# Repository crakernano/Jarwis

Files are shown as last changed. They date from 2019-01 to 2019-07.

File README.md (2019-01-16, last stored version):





## ¿Qué es Jarwis?
Jarwis es la versión simplificada basada en web del sistema domotico de control JARVIS https://github.com/makespacemadrid/Jarvis

Basado en los modulos de bajo coste NodeMCU y controlado desde una Raspberry Pi que se encarga del automatismo y control de todos los módulo. La comunicación se establece por WiFi y un sistema basado en comunicaciones WEB permite monitorizar distintos parametros tales como:

⋅⋅* Humedad
⋅⋅* Temperatura
⋅⋅* Luz

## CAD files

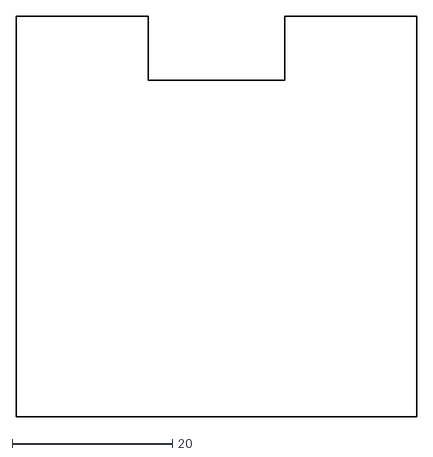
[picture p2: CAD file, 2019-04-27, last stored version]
Modulos/jarwis/placa.dxf
50.0 x 50.0

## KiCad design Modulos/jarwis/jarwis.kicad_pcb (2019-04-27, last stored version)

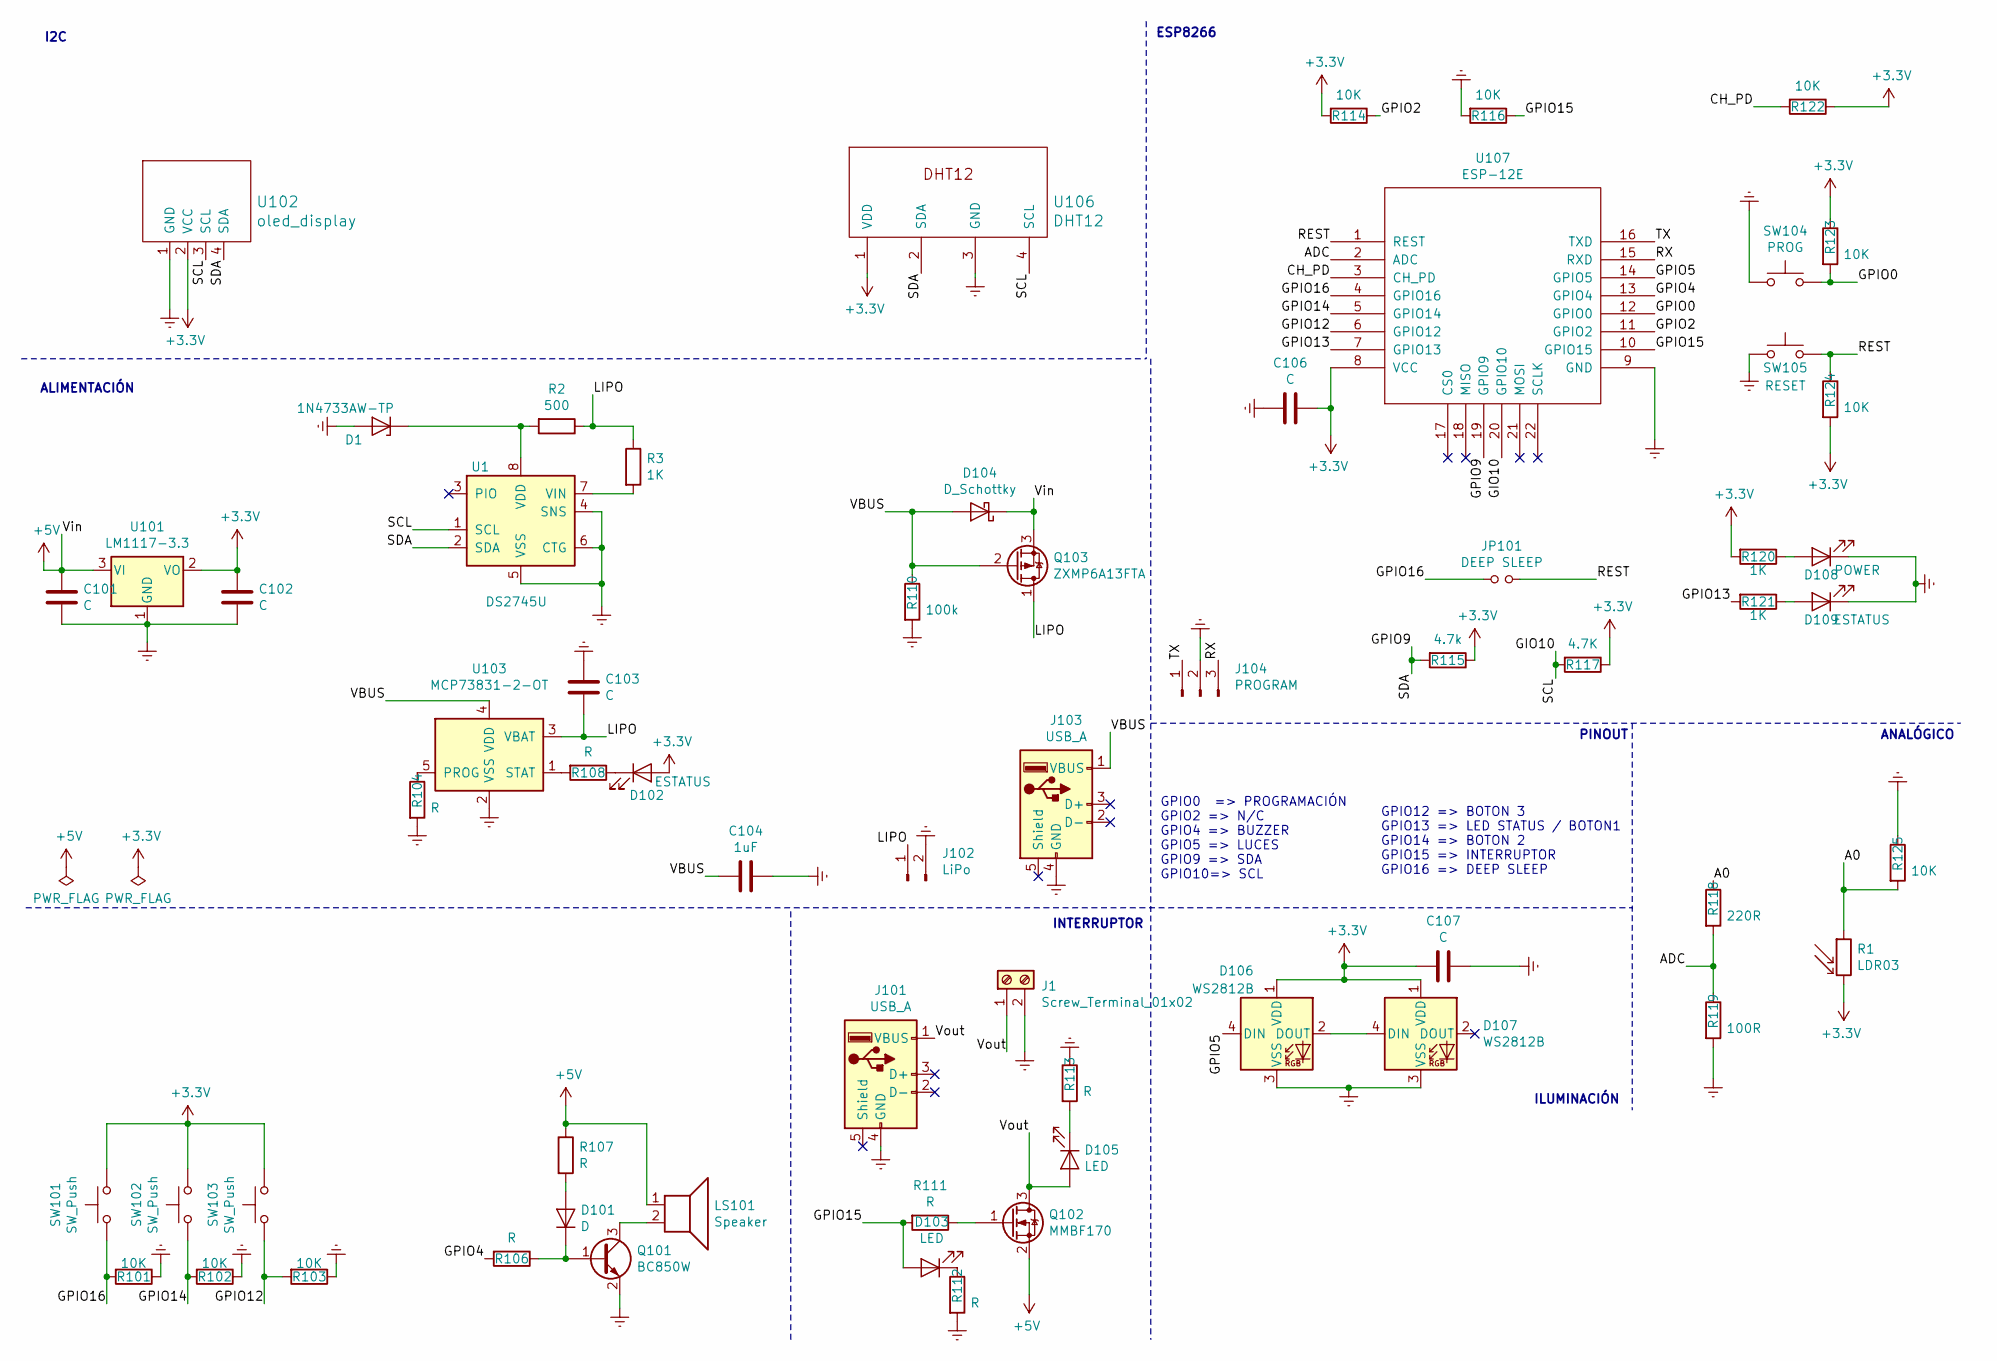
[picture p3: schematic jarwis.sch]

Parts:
C101, C102, C103, C106, C107: C; C_0805_2012Metric_Pad1.15x1.40mm_HandSolder
C104: 1uF; C_0805_2012Metric_Pad1.15x1.40mm_HandSolder
D1: 1N4733AW-TP; D_0805_2012Metric_Pad1.15x1.40mm_HandSolder
D101: D; D_0805_2012Metric_Pad1.15x1.40mm_HandSolder
D102, D109: ESTATUS; LED_0805_2012Metric_Pad1.15x1.40mm_HandSolder
D103, D105: LED; LED_0805_2012Metric_Pad1.15x1.40mm_HandSolder
D104: D_Schottky; D_0805_2012Metric_Pad1.15x1.40mm_HandSolder
D106, D107: WS2812B; LED_WS2812B_PLCC4_5.0x5.0mm_P3.2mm
D108: POWER; LED_0805_2012Metric_Pad1.15x1.40mm_HandSolder
J1: Screw_Terminal_01x02; TerminalBlock_bornier-2_P5.08mm
J101: USB_A; FCI_87520-0010BLF
J102: LiPo; PinHeader_1x02_P2.54mm_Vertical
J103: USB_A; USB_Micro-B_Wuerth_629105150521_CircularHoles
J104: PROGRAM; PinHeader_1x03_P2.54mm_Vertical
JP101: DEEP SLEEP; SolderJumper-2_P1.3mm_Open_RoundedPad1.0x1.5mm
LS101: Speaker; MagneticBuzzer_Kingstate_KCG0601
Q101: BC850W; SOT-323_SC-70
Q102: MMBF170; SOT-23
Q103: ZXMP6A13FTA; SOT-23_Handsoldering
R1: LDR03; R_LDR_7x6mm_P5.1mm_Vertical
R2: 500; R_0805_2012Metric_Pad1.15x1.40mm_HandSolder
R3, R120, R121: 1K; R_0805_2012Metric_Pad1.15x1.40mm_HandSolder
R101, R102, R103, R114, R116, R122, R123, R124, R125: 10K; R_0805_2012Metric_Pad1.15x1.40mm_HandSolder
R104, R106, R107, R108, R111, R112, R113: R; R_0805_2012Metric_Pad1.15x1.40mm_HandSolder
R110: 100k; R_0805_2012Metric_Pad1.15x1.40mm_HandSolder
R115: 4.7k; R_0805_2012Metric_Pad1.15x1.40mm_HandSolder
R117: 4.7K; R_0805_2012Metric_Pad1.15x1.40mm_HandSolder
R118: 220R; R_0805_2012Metric_Pad1.15x1.40mm_HandSolder
R119: 100R; R_0805_2012Metric_Pad1.15x1.40mm_HandSolder
SW101, SW102, SW103: SW_Push; SW_SPST_B3S-1000
SW104: PROG; SW_Tactile_SPST_Angled_PTS645Vx31-2LFS
SW105: RESET; SW_Tactile_SPST_Angled_PTS645Vx31-2LFS
U1: DS2745U; TSSOP-8_3x3mm_P0.65mm
U101: LM1117-3.3; SOT-223-3_TabPin2
U102: oled_display; oled_display_0.96
U103: MCP73831-2-OT; SOT-23-5
U106: DHT12
U107: ESP-12E; ESP-12E_SMD

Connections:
+3V3: C102.1, C106.1, C107.2, D102.2 (A), D106.1 (VDD), D107.1 (VDD), R1.2, R114.2, R115.1, R117.1, R120.2, R122.1, R123.1, R124.2, SW101.2, SW102.2, SW103.2, U101.2 (VO), U102.2 (VCC), U106.1 (VDD), U107.8 (VCC)
+5V: C101.1, D104.1 (K), LS101.1, Q102.2 (S), Q103.3 (S), R107.1, U101.3 (VI)
/A0: R1.1, R118.1, R125.2
/ADC: R118.2, R119.1, U107.2 (ADC)
/CH_PD: R122.2, U107.3 (CH_PD)
/GIO10: R117.2, U1.1 (SCL), U102.3 (SCL), U106.4 (SCL), U107.20 (GPIO10)
/GPIO0: R123.2, SW104.2, U107.12 (GPIO0)
/GPIO2: R114.1, U107.11 (GPIO2)
/GPIO4: R106.2, U107.13 (GPIO4)
/GPIO5: D106.4 (DIN), U107.14 (GPIO5)
/GPIO9: R115.2, U1.2 (SDA), U102.4 (SDA), U106.2 (SDA), U107.19 (GPIO9)
/GPIO12: R103.2, SW103.1, U107.6 (GPIO12)
/GPIO13: R121.2, U107.7 (GPIO13)
/GPIO14: R102.2, SW102.1, U107.5 (GPIO14)
/GPIO15: D103.2 (A), R111.2, R116.1, U107.10 (GPIO15)
/GPIO16: JP101.1, R101.2, SW101.1, U107.4 (GPIO16)
/LIPO: C103.2, J102.1, Q103.1 (D), R2.1, R3.1, U103.3 (VBAT)
/REST: JP101.2, R124.1, SW105.2, U107.1 (REST)
/RX: J104.3, U107.15 (RXD)
/TX: J104.1, U107.16 (TXD)
/VBUS: C104.2, D104.2 (A), J103.1 (VBUS), Q103.2 (G), R110.1, U103.4 (VDD)
/Vout: D105.2 (A), J1.1, J101.1 (VBUS), Q102.3 (D)
Earth: C101.2, C102.2, C103.1, C104.1, C106.2, C107.1, D1.2 (A), D106.3 (VSS), D107.3 (VSS), D108.1 (K), D109.1 (K), J1.2, J101.4 (GND), J102.2, J103.4 (GND), J104.2, Q101.2 (E), R101.1, R102.1, R103.1, R104.2, R110.2, R112.2, R113.1, R116.2, R119.2, R125.1, SW104.1, SW105.1, U1.4 (SNS), U1.5 (VSS), U1.6 (CTG), U101.1 (GND), U102.1 (GND), U103.2 (VSS), U106.3 (GND), U107.9 (GND)
unnamed: D1.1 (K), R2.2, U1.8 (VDD)
unnamed: D101.1 (K), Q101.1 (B), R106.1
unnamed: D101.2 (A), R107.2
unnamed: D102.1 (K), R108.1
unnamed: D103.1 (K), R112.1
unnamed: D105.1 (K), R113.2
unnamed: D106.2 (DOUT), D107.4 (DIN)
unnamed: D108.2 (A), R120.1
unnamed: D109.2 (A), R121.1
unnamed: LS101.2, Q101.3 (C)
unnamed: Q102.1 (G), R111.1
unnamed: R3.2, U1.7 (VIN)
unnamed: R104.1, U103.5 (PROG)
unnamed: R108.2, U103.1 (STAT)

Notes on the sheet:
PINOUT
GPIO0 => PROGRAMACIÓN GPIO2 => N/C GPIO4 => BUZZER GPIO5 => LUCES GPIO9 => SDA GPIO10=> SCL
GPIO12 => BOTON 3 GPIO13 => LED STATUS / BOTON1 GPIO14 => BOTON 2 GPIO15 => INTERRUPTOR GPIO16 => DEEP SLEEP
I2C
ALIMENTACIÓN
ESP8266
ANALÓGICO
INTERRUPTOR
ILUMINACIÓN

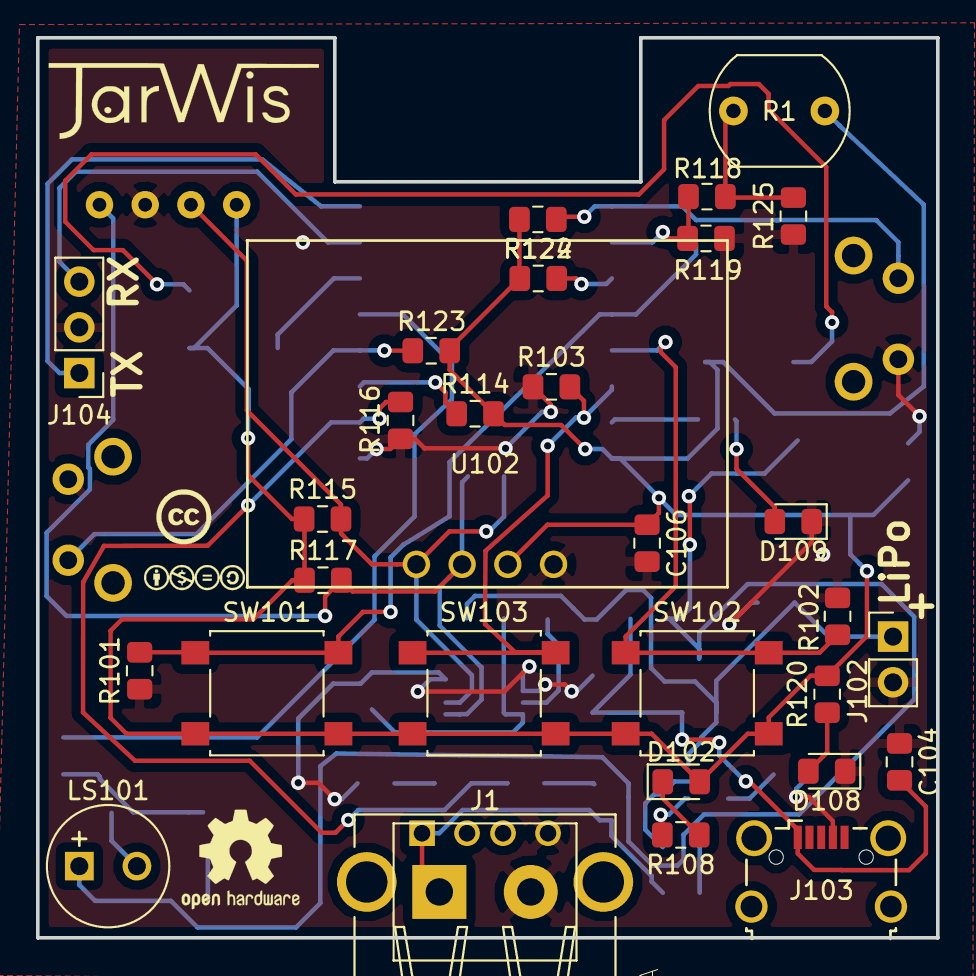
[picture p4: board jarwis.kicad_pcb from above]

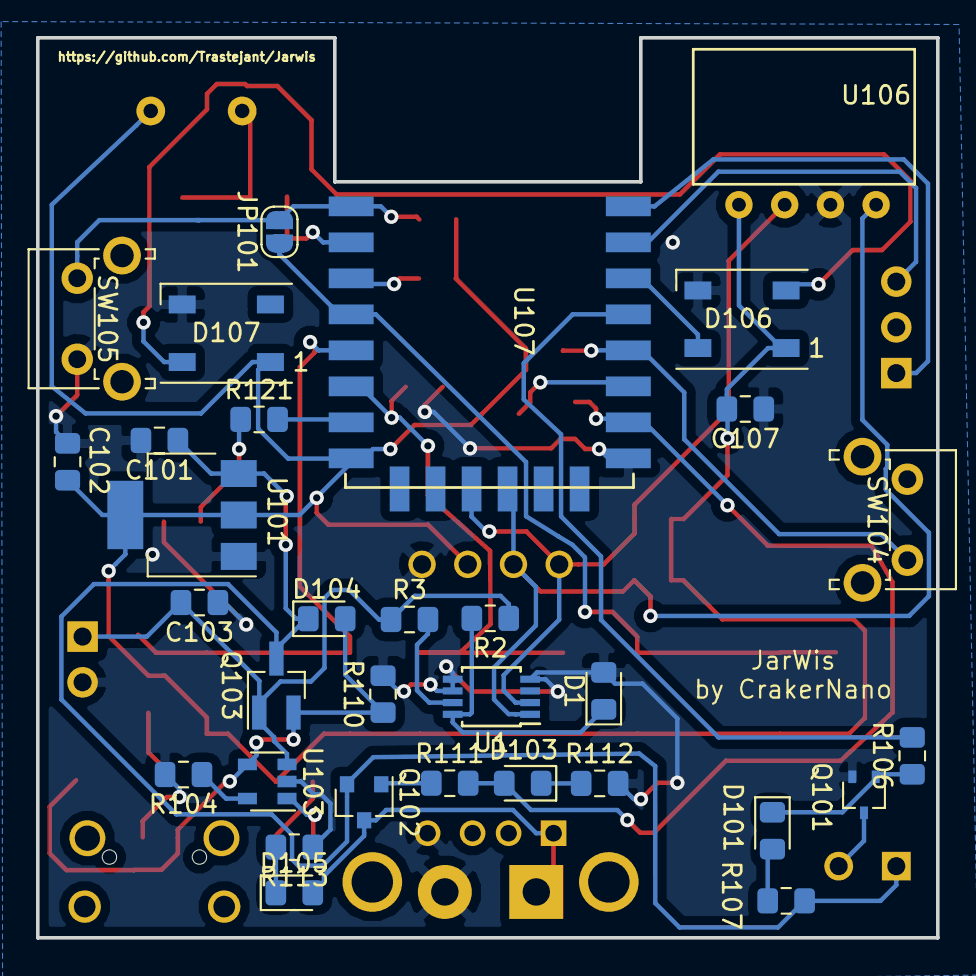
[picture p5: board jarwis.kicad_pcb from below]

Board: 2 copper layers, 50.0 x 50.0 mm, 63 parts (32 on the bottom side), 37 nets.

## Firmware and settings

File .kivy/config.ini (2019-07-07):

[kivy]
keyboard_repeat_delay = 300
keyboard_repeat_rate = 30
log_dir = logs
log_enable = 1
log_level = info
log_name = kivy_%y-%m-%d_%_.txt
window_icon = 
keyboard_mode = 
keyboard_layout = qwerty
desktop = 1
exit_on_escape = 1
pause_on_minimize = 0
kivy_clock = default
default_font = ['Roboto', 'data/fonts/Roboto-Regular.ttf', 'data/fonts/Roboto-Italic.ttf', 'data/fonts/Roboto-Bold.ttf', 'data/fonts/Roboto-BoldItalic.ttf']
log_maxfiles = 100
window_shape = data/images/defaultshape.png
config_version = 20

[graphics]
display = -1
fullscreen = 0
height = 600
left = 0
maxfps = 60
multisamples = 2
position = auto
rotation = 0
show_cursor = 1
top = 0
width = 800
resizable = 1
borderless = 0
window_state = visible
minimum_width = 0
minimum_height = 0
min_state_time = .035
allow_screensaver = 1
shaped = 0


[postproc]
double_tap_distance = 20
double_tap_time = 250
ignore = []
jitter_distance = 0
jitter_ignore_devices = mouse,mactouch,
retain_distance = 50
retain_time = 0
triple_tap_distance = 20
triple_tap_time = 375

[widgets]
scroll_timeout = 250
scroll_distance = 20
scroll_friction = 1.
scroll_stoptime = 300
scroll_moves = 5

[modules]

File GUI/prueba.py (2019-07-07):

 #!/usr/bin/env python3
    # -*- coding: utf-8 -*-

    from kivy.app import App
    from kivy.clock import Clock
    from kivy.uix.screenmanager import ScreenManager, Screen
    from kivy.uix.boxlayout import BoxLayout
    from kivy.properties import ObjectProperty, StringProperty
    import paho.mqtt.client as mqtt
    import RPi.GPIO as GPIO
    import json
    import time, datetime

    class ScreenManagement(ScreenManager):
        pass

    class Main(Screen):
        inoutflow = StringProperty()
        freshexh = StringProperty()
        tacho = StringProperty()
        co2 = StringProperty()
        def setVent(self,percent):
            print('button state is: ', percent)
            message = "{\"flow-rate\":\"" + str(percent) + "\"}"
            mqttc.publish('weigus/attic/attic/ventilation',message)

    class Setup(Screen):
        pass

    class pitouconApp(App):
        def build(self):
            global SM #ScreenManager
            global s
            SM = self.root
            s = SM.get_screen('main')

        def on_start(self):
            global mqttc
            global switch_pin
            switch_pin = 3
            global switch_old
            switch_old = 1
            GPIO.setmode(GPIO.BCM)
            GPIO.setwarnings(False)
            GPIO.setup(switch_pin, GPIO.IN)
            clientID   = "pitoucon"
            brokerIP   = "192.168.1.111"
            brokerPort = 1883
            topic      = "mytopic"
            # Callback if CONNACK response from the server.
            def onConnect(client, userdata, flags, rc):
                print("Connected with result code " + str(rc))
                mqttc.subscribe(topic, 0)  # Subscribe (topic name, QoS)
            # Callback that is executed when we disconnect from the broker.
            def onDisconnect(client, userdata, message):
                print("Disconnected from the broker.")
            # Callback that is executed when subscribing to a topic
            def onSubscribe(client, userdata, mid, granted_qos):
                print('Subscribed on topic.')
            # Callback that is executed when unsubscribing to a topic
            def onUnsubscribe(client, userdata, mid, granted_qos):
                print('Unsubscribed on topic.')
            # Callback that is executed when a message is received.
            def onMessage(client, userdata, message):
                io=message.payload.decode("utf-8")
                if (io[2:6] != "flow") and (io[2:7] != "alive"):
                    try:
                        ioj=json.loads(io)
                        inflowTxt = ioj["inflow"]
                        outflowTxt = ioj["outflow"]
                        inOutTxt = "Temp   Hum      \n" + inflowTxt + "  IN \n\n" + outflowTxt + "  OUT"
                        s.inoutflow = inOutTxt
                        freshTxt = ioj["fresh"]
                        exhaustTxt = ioj["exhaust"]
                        freExTxt = "        Temp   Hum\nFRESH   " + freshTxt + "\n\nEXHAUST " + exhaustTxt
                        s.freshexh = freExTxt
                        tinTxt = ioj["tacho-in"]
                        if tinTxt[2]  == "%":
                            tinTxt = tinTxt[0:2]
                        else:
                            tinTxt = tinTxt[0:3]
                        toutTxt = ioj["tacho-out"]
                        if toutTxt[2]  == "%":
                            toutTxt = toutTxt[0:2]
                        else:
                            toutTxt = toutTxt[0:3]
                        tachoTxt = "Tacho I/O : " + tinTxt + "% " + toutTxt + "%"
                        s.tacho = tachoTxt
                        co2Txt = ioj["co2"]
                        co2Txt = "CO: " + co2Txt
                        s.co2 = co2Txt
                    except:
                       print("json error")
                else:
                    pass
            # Callback every 500ms to poll the backlight switch and act accordingly
            def poll_switch(dt):
                global switch_old
                switch = GPIO.input(switch_pin)
                if (switch != switch_old):
                    if switch:
                        with open("/sys/class/backlight/soc:backlight/brightness", "w") as f:
                            f.write('0')
                    else:
                        with open("/sys/class/backlight/soc:backlight/brightness", "w") as f:
                            f.write('1')
                switch_old = switch
            def send_alive(dt):
                samessage = datetime.datetime.now().strftime('%Y/%m/%d %H:%M:%S')
                samessage = "{\"alive\":\"" + samessage + "\"}"
                mqttc.publish('weigus/attic/attic/ventilation',samessage)

            mqttc = mqtt.Client(client_id=clientID, clean_session=True)
            mqttc.on_connect      = onConnect   # define the callback functions
            mqttc.on_disconnect   = onDisconnect
            mqttc.on_subscribe    = onSubscribe
            mqttc.on_unsubscribe  = onUnsubscribe
            mqttc.on_message      = onMessage
            mqttc.connect(brokerIP, brokerPort, keepalive=60, bind_address="")
            mqttc.loop_start() # start loop to process callbacks! (new thread!)
            event = Clock.schedule_interval(poll_switch, 1 / 2.) # poll switch 500ms
            event = Clock.schedule_interval(send_alive, 600) # send alive 10 min.
    if __name__ == "__main__":
        pitouconApp().run()

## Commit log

2019-01-25 Firmware de la estación meteorolica externa de Jarwis
2019-01-28 Añadido el Firmware para el Attiny de los modulos JGG
    Esta versión es capaz de emitir por 433Mhz las lecturas de humedad del suelo y luminosidad
    Working progress:
    La librería para leer el sensor de humedad ambiental y temperatura por i2c no funciona correctamente
    Falta la comunicación I2C entre el Attiny85 y el ESP8266
2019-04-27 PCB del modulo principal de Jarwis (En pruebas)
    [jarwis.kicad_pcb, jarwis.sch, jarwis_bom_.csv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]
2019-04-27 Imagenes de la PCB
2019-06-23 Librerias Python para el servidor
2019-07-07 Pendiente de limpieza
    [jarwis.kicad_pcb, jarwis.sch, jarwis_bom_.csv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]
